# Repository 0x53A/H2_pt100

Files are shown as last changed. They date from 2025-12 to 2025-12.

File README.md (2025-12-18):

This project contains the firmware for the STM32 Nucelo board that's used to measure electrolyte in- and outflow temperatures using PT100 probes at the big ely test station.

The firmware is in ./mcu-stm32g4.

In ./app, there's a small TUI that reads received data from UART.

In ./analysis there's the worksheet that was used for 2-point calibration.

The ROS Node which receives the data ignores the temperatures calculated internally by the firmware (which are inaccurate) and recalculates based on the worksheet:

For board #1:

```
=== Calibration Coefficients ===
PT100 #1: T = 0.008517 * ADC + (-270.186)
PT100 #2: T = 0.008559 * ADC + (-269.970)
```

For board #2:

```
=== Calibration Coefficients ===
PT100 #1: T = 0.008611 * ADC + (-270.310)
PT100 #2: T = 0.008665 * ADC + (-272.644)
```

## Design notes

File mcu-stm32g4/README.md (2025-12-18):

Chip: stm32g431kb

Based on example https://github.com/embassy-rs/embassy/tree/main/examples/stm32g4

## Pin Configuration

### ADC

On the Nucleo Board, CN3:[7,8] (PA5/PA6) are used for I2C, CN3:[5,10] (PA2/PA3) are used for UART. This leaves PA0, PA1, PA4, PA7 as analog-capable pins.

### OpAmp

To use the OpAmp in buffer mode, we need to connect OPAMPx_VINP to the signal we want to measure.

Potential Pins:

| Pin | Func |
| -- | -- |
| PA1 | OPAMP1_VINP, OPAMP3_VINP |
| ~PA3~ | _(PA3 is used for UART)_ |
| PA7 | OPAMP1_VINP, OPAMP2_VINP |
| PB0 | OPAMP2_VINP, OPAMP3_VINP |
| ~PB13~ | OPAMP3_VINP |
| ~PB14~ | OPAMP2_VINP |
| ~PD14~ | OPAMP2_VINP |

### Usage

There is an approximately 3.2 kΩ series resistor between V_3.3 and the PT100. The PT100 are connected via PA7 and PB0 to OpAmp#2, which amplifies the signal by x16 and feeds it into ADC#2.

Data is output through the ST-Link via UART at PA2.

The firmware calculates temperature based on the series resistor values, but that is extremely inaccurate and should be ignored. Instead, the receiver should calculate the temperature based on the raw ADC values and a two-point calculation, which needs to be done for each board seperately.

## Setup

Install Rust using [rustup](https://rustup.rs/).

```sh
# once
cargo install probe-rs-tools

# compile, flash and run, monitor output
cargo run --release

# monitor the output of a running mcu without resetting it
probe-rs attach ./target/thumbv7em-none-eabi/release/pt100_stm32g4 --chip STM32G431KB
```

---

Board:
NUCLEO-G431KB
https://www.st.com/en/evaluation-tools/nucleo-g431kb.html

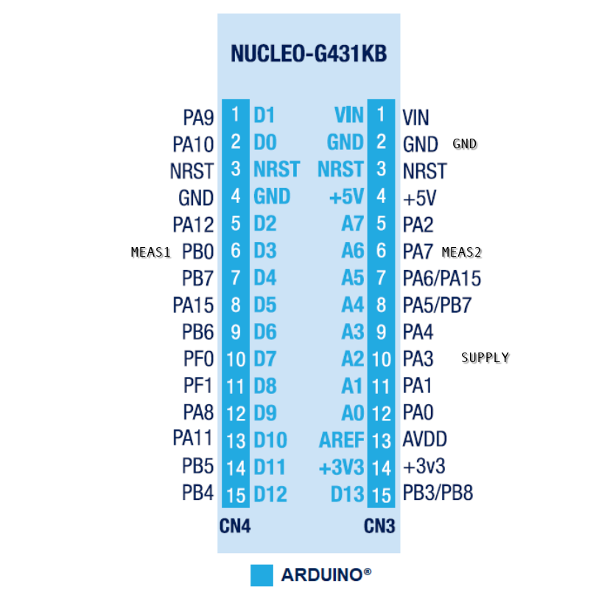
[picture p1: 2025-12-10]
mcu-stm32g4/schematic/Screenshot_20251209_223936.png

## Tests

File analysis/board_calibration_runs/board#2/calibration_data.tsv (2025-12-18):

timestamp | boot_id | sampling_resolution_bits | sampling_sample_time_cycles | sampling_oversampling | sampling_n_measurements | sampling_amplification | pt100_1_series_resistor_ohms | pt100_2_series_resistor_ohms | raw_pt100_1_p20 | raw_pt100_1_median | raw_pt100_1_p80 | raw_pt100_2_p20 | raw_pt100_2_median | raw_pt100_2_p80 | pt100_1_r_pt | pt100_1_temperature | pt100_2_r_pt | pt100_2_temperature
2025-12-17T15:22:55.402Z | 3143733478 | 12 | 640 | 256 | 30 | 16 | 3183.6 | 3203.3 | 31412 | 31418 | 31420 | 31470 | 31475 | 31480 | 98.33666 | -4.320358 | 99.13023 | -2.259133
2025-12-17T15:22:55.677Z | 3143733478 | 12 | 640 | 256 | 30 | 16 | 3183.6 | 3203.3 | 31410 | 31414 | 31416 | 31468 | 31472 | 31475 | 98.32375 | -4.3538876 | 99.12049 | -2.2844388
2025-12-17T15:22:55.952Z | 3143733478 | 12 | 640 | 256 | 30 | 16 | 3183.6 | 3203.3 | 31408 | 31412 | 31418 | 31467 | 31472 | 31477 | 98.3173 | -4.370652 | 99.12049 | -2.2844388
2025-12-17T15:22:56.227Z | 3143733478 | 12 | 640 | 256 | 30 | 16 | 3183.6 | 3203.3 | 31410 | 31414 | 31419 | 31465 | 31471 | 31477 | 98.32375 | -4.3538876 | 99.11724 | -2.2928808
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

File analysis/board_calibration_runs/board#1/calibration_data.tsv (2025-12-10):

timestamp | boot_id | sampling_resolution_bits | sampling_sample_time_cycles | sampling_oversampling | sampling_n_measurements | sampling_amplification | pt100_1_series_resistor_ohms | pt100_2_series_resistor_ohms | raw_pt100_1_p20 | raw_pt100_1_median | raw_pt100_1_p80 | raw_pt100_2_p20 | raw_pt100_2_median | raw_pt100_2_p80 | pt100_1_r_pt | pt100_1_temperature | pt100_2_r_pt | pt100_2_temperature
2025-12-10T13:20:28.790Z | 4221434046 | 12 | 640 | 256 | 10 | 16 | 3183.6 | 3203.3 | 34457 | 34459 | 34463 | 34256 | 34258 | 34263 | 108.17825 | 21.242216 | 108.1913 | 21.276102
2025-12-10T13:20:28.850Z | 4221434046 | 12 | 640 | 256 | 10 | 16 | 3183.6 | 3203.3 | 34453 | 34459 | 34466 | 34256 | 34257 | 34261 | 108.17825 | 21.242216 | 108.188034 | 21.267622
2025-12-10T13:20:28.906Z | 4221434046 | 12 | 640 | 256 | 10 | 16 | 3183.6 | 3203.3 | 34454 | 34459 | 34462 | 34253 | 34255 | 34261 | 108.17825 | 21.242216 | 108.1815 | 21.250658
2025-12-10T13:20:28.962Z | 4221434046 | 12 | 640 | 256 | 10 | 16 | 3183.6 | 3203.3 | 34453 | 34457 | 34463 | 34254 | 34255 | 34259 | 108.17176 | 21.225353 | 108.1815 | 21.250658
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

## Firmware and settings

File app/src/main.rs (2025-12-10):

use anyhow::{Context, Result};
use chrono::Utc;
use clap::Parser;
use common::UartOutput;
use crossterm::{
    event::{self, Event, KeyCode, KeyEventKind},
    terminal::{disable_raw_mode, enable_raw_mode, EnterAlternateScreen, LeaveAlternateScreen},
    ExecutableCommand,
};
use ratatui::{
    backend::CrosstermBackend,
    layout::{Constraint, Direction, Layout, Rect},
    style::{Color, Modifier, Style},
    text::{Line, Span},
    widgets::{Block, Borders, List, ListItem, ListState, Paragraph},
    Frame, Terminal,
};
use std::{
    fs::{File, OpenOptions},
    io::{self, stdout, BufRead, BufReader, Write},
    path::PathBuf,
    time::{Duration, Instant},
};

const COMMON_BAUD_RATES: &[u32] = &[9600, 19200, 38400, 57600, 115200, 230400, 460800, 921600];

#[derive(Parser, Debug)]
#[command(author, version, about, long_about = None)]
struct Args {
    /// Serial port path (e.g., /dev/ttyACM0)
    #[arg(short, long)]
    port: Option<String>,

    /// Baud rate
    #[arg(short, long)]
    baud: Option<u32>,

    /// Log file directory (defaults to current directory)
    #[arg(short, long)]
    log_dir: Option<PathBuf>,
}

#[derive(Clone, Copy, PartialEq)]
enum SelectionMode {
    Port,
    Baud,
}

#[derive(Clone, Copy, PartialEq)]
enum AppState {
    SelectingPort,
    SelectingBaud,
    Connected,
    Disconnected,
}

struct App {
    state: AppState,
    port: Option<String>,
    baud: Option<u32>,
    log_dir: PathBuf,
    log_file: Option<File>,
    last_output: Option<UartOutput>,
    last_received: Option<Instant>,
    available_ports: Vec<String>,
    list_state: ListState,
    error_counter: u32,
    status_message: String,
    last_flush: Instant,
}

impl App {
    fn new(args: Args) -> Self {
        let log_dir = args.log_dir.unwrap_or_else(|| std::env::current_dir().unwrap_or_default());
        
        let initial_state = if args.port.is_none() {
            AppState::SelectingPort
        } else if args.baud.is_none() {
            AppState::SelectingBaud
        } else {
            AppState::Disconnected
        };

        let mut app = App {
            state: initial_state,
            port: args.port,
            baud: args.baud,
            log_dir,
            log_file: None,
            last_output: None,
            last_received: None,
            available_ports: Vec::new(),
            list_state: ListState::default(),
            error_counter: 0,
            status_message: String::new(),
            last_flush: Instant::now(),
        };
        
        if app.state == AppState::SelectingPort {
            app.refresh_ports();
        }
        
        app
    }

    fn refresh_ports(&mut self) {
        self.available_ports = serialport::available_ports()
            .map(|ports| ports.into_iter().map(|p| p.port_name).collect())
            .unwrap_or_default();
        
        if !self.available_ports.is_empty() && self.list_state.selected().is_none() {
            self.list_state.select(Some(0));
        }
    }

    fn select_next(&mut self) {
        let len = match self.state {
            AppState::SelectingPort => self.available_ports.len(),
            AppState::SelectingBaud => COMMON_BAUD_RATES.len(),
            _ => return,
        };
        
        if len == 0 {
            return;
        }
        
        let i = match self.list_state.selected() {
            Some(i) => (i + 1) % len,
            None => 0,
        };
        self.list_state.select(Some(i));
    }

    fn select_previous(&mut self) {
        let len = match self.state {
            AppState::SelectingPort => self.available_ports.len(),
            AppState::SelectingBaud => COMMON_BAUD_RATES.len(),
            _ => return,
        };
        
        if len == 0 {
            return;
        }
        
        let i = match self.list_state.selected() {
            Some(i) => {
                if i == 0 {
                    len - 1
                } else {
                    i - 1
                }
            }
            None => 0,
        };
        self.list_state.select(Some(i));
    }

    fn confirm_selection(&mut self) {
        match self.state {
            AppState::SelectingPort => {
                if let Some(i) = self.list_state.selected() {
                    if let Some(port) = self.available_ports.get(i) {
                        self.port = Some(port.clone());
                        if self.baud.is_none() {
                            self.state = AppState::SelectingBaud;
                            self.list_state.select(Some(4)); // Default to 115200
                        } else {
                            self.state = AppState::Disconnected;
                        }
                    }
                }
            }
            AppState::SelectingBaud => {
                if let Some(i) = self.list_state.selected() {
                    if let Some(&baud) = COMMON_BAUD_RATES.get(i) {
                        self.baud = Some(baud);
                        self.state = AppState::Disconnected;
                    }
                }
            }
            _ => {}
        }
    }

    fn open_log_file(&mut self) -> Result<()> {
        let date = Utc::now().format("%Y-%m-%d_%H-%M-%S");
        let filename = format!("{}-temperatures.tsv", date);
        let path = self.log_dir.join(&filename);
        
        let file_exists = path.exists();
        
        let file = OpenOptions::new()
            .create(true)
            .append(true)
            .open(&path)
            .with_context(|| format!("Failed to open log file: {:?}", path))?;
        
        self.log_file = Some(file);
        
        // Write header if file is new
        if !file_exists {
            self.write_tsv_header()?;
        }
        
        self.status_message = format!("Logging to: {:?}", path);
        Ok(())
    }

    fn write_tsv_header(&mut self) -> Result<()> {
        if let Some(ref mut file) = self.log_file {
            writeln!(
                file,
                "timestamp\tboot_id\t\
                sampling_resolution_bits\tsampling_sample_time_cycles\tsampling_oversampling\tsampling_n_measurements\tsampling_amplification\t\
                pt100_1_series_resistor_ohms\tpt100_2_series_resistor_ohms\t\
                raw_pt100_1_p20\traw_pt100_1_median\traw_pt100_1_p80\t\
                raw_pt100_2_p20\traw_pt100_2_median\traw_pt100_2_p80\t\
                pt100_1_r_pt\tpt100_1_temperature\t\
                pt100_2_r_pt\tpt100_2_temperature"
            )?;
        }
        Ok(())
    }

    fn write_tsv_row(&mut self, output: &UartOutput) -> Result<()> {
        if let Some(ref mut file) = self.log_file {
            let timestamp = Utc::now().format("%Y-%m-%dT%H:%M:%S%.3fZ");
            writeln!(
                file,
                "{}\t{}\t\
                {}\t{}\t{}\t{}\t{}\t\
                {}\t{}\t\
                {}\t{}\t{}\t\
                {}\t{}\t{}\t\
                {}\t{}\t\
                {}\t{}",
                timestamp,
                output.boot_id,
                output.config.sampling.resolution_bits,
                output.config.sampling.sample_time_cycles,
                output.config.sampling.oversampling,
                output.config.sampling.n_measurements,
                output.config.sampling.amplification,
                output.config.pt100_1_series_resistor_ohms,
                output.config.pt100_2_series_resistor_ohms,
                output.raw.pt100_1.p20,
                output.raw.pt100_1.median,
                output.raw.pt100_1.p80,
                output.raw.pt100_2.p20,
                output.raw.pt100_2.median,
                output.raw.pt100_2.p80,
                output.calculated.pt100_1.r_pt,
                output.calculated.pt100_1.temperature,
                output.calculated.pt100_2.r_pt,
                output.calculated.pt100_2.temperature,
            )?;
        }
        Ok(())
    }

    fn flush_if_needed(&mut self) {
        if self.last_flush.elapsed() >= Duration::from_secs(1) {
            self.flush();
        }
    }

    fn flush(&mut self) {
        if let Some(ref mut file) = self.log_file {
            let _ = file.flush();
        }
        self.last_flush = Instant::now();
    }
}

fn main() -> Result<()> {
    let args = Args::parse();
    let mut app = App::new(args);

    // Setup terminal
    enable_raw_mode()?;
    stdout().execute(EnterAlternateScreen)?;
    let backend = CrosstermBackend::new(stdout());
    let mut terminal = Terminal::new(backend)?;

    let result = run_app(&mut terminal, &mut app);

    // Restore terminal
    disable_raw_mode()?;
    stdout().execute(LeaveAlternateScreen)?;

    result
}

fn run_app<B: ratatui::backend::Backend>(terminal: &mut Terminal<B>, app: &mut App) -> Result<()> {
    let mut serial_reader: Option<BufReader<Box<dyn serialport::SerialPort>>> = None;
    let mut line_buffer = String::new();

    loop {
        terminal.draw(|f| ui(f, app))?;

        // Handle connection attempts in Disconnected state
        if app.state == AppState::Disconnected && serial_reader.is_none() {
            if let (Some(port), Some(baud)) = (&app.port, app.baud) {
                match serialport::new(port, baud)
                    .timeout(Duration::from_millis(100))
                    .open()
                {
                    Ok(port) => {
                        serial_reader = Some(BufReader::with_capacity(20_000, port));
                        app.state = AppState::Connected;
                        app.status_message = format!("Connected to {} @ {}", app.port.as_ref().unwrap(), baud);
                        
                        if app.log_file.is_none() {
                            if let Err(e) = app.open_log_file() {
                                app.status_message = format!("Error opening log: {}", e);
                            }
                        }
                    }
                    Err(e) => {
                        app.status_message = format!("Connection failed: {} - retrying...", e);
                        app.refresh_ports();
                    }
                }
            }
        }

        // Read from serial if connected
        if app.state == AppState::Connected {
            if let Some(ref mut reader) = serial_reader {
                line_buffer.clear();
                match reader.read_line(&mut line_buffer) {
                    Ok(0) => {
                        // EOF - disconnected
                        app.state = AppState::Disconnected;
                        app.status_message = "Disconnected (EOF)".to_string();
                        serial_reader = None;
                        app.flush();
                    }
                    Ok(_) => {
                        let line = line_buffer.trim();
                        if !line.is_empty() {
                            match serde_json::from_str::<UartOutput>(line) {
                                Ok(output) => {
                                    if let Err(e) = app.write_tsv_row(&output) {
                                        app.error_counter += 1;
                                        app.status_message = format!("[{}] Write error: {}", app.error_counter, e);
                                    }
                                    app.last_output = Some(output);
                                    app.last_received = Some(Instant::now());
                                }
                                Err(e) => {
                                    app.error_counter += 1;
                                    app.status_message = format!("[{}] Parse error: {} ({})", app.error_counter, e, line[..20].to_string());
                                }
                            }
                        }
                    }
                    Err(ref e) if e.kind() == io::ErrorKind::TimedOut => {
                        // Normal timeout, continue
                    }
                    Err(e) => {
                        app.state = AppState::Disconnected;
                        app.error_counter += 1;
                        app.status_message = format!("[{}] Read error: {}", app.error_counter, e);
                        serial_reader = None;
                        app.flush();
                    }
                }
            }
        }

        app.flush_if_needed();

        // Handle keyboard events (with timeout to not block serial reading)
        if event::poll(Duration::from_millis(50))? {
            if let Event::Key(key) = event::read()? {
                if key.kind == KeyEventKind::Press {
                    match key.code {
                        KeyCode::Char('q') | KeyCode::Esc => {
                            app.flush();
                            return Ok(());
                        }
                        KeyCode::Up | KeyCode::Char('k') => app.select_previous(),
                        KeyCode::Down | KeyCode::Char('j') => app.select_next(),
                        KeyCode::Enter => app.confirm_selection(),
                        KeyCode::Char('r') => {
                            if app.state == AppState::SelectingPort {
                                app.refresh_ports();
                            }
                        }
                        _ => {}
                    }
                }
            }
        }
    }
}

fn ui(f: &mut Frame, app: &App) {
    let chunks = Layout::default()
        .direction(Direction::Vertical)
        .constraints([
            Constraint::Length(3), // Status bar
            Constraint::Min(10),   // Main content
            Constraint::Length(3), // Help bar
        ])
        .split(f.area());

    // Status bar
    let status_text = match app.state {
        AppState::SelectingPort => "Select Serial Port".to_string(),
        AppState::SelectingBaud => "Select Baud Rate".to_string(),
        AppState::Connected => format!(
            "Connected: {} @ {}",
            app.port.as_ref().unwrap_or(&"?".to_string()),
            app.baud.unwrap_or(0)
        ),
        AppState::Disconnected => format!(
            "Disconnected: {} @ {} - Waiting for reconnect...",
            app.port.as_ref().unwrap_or(&"?".to_string()),
            app.baud.unwrap_or(0)
        ),
    };
    
    let status_style = match app.state {
        AppState::Connected => Style::default().fg(Color::Green),
        AppState::Disconnected => Style::default().fg(Color::Yellow),
        _ => Style::default().fg(Color::Cyan),
    };
    
    let status = Paragraph::new(status_text)
        .style(status_style)
        .block(Block::default().borders(Borders::ALL).title("Status"));
    f.render_widget(status, chunks[0]);

    // Main content area
    match app.state {
        AppState::SelectingPort => {
            render_port_selection(f, app, chunks[1]);
        }
        AppState::SelectingBaud => {
            render_baud_selection(f, app, chunks[1]);
        }
        AppState::Connected | AppState::Disconnected => {
            render_temperature_display(f, app, chunks[1]);
        }
    }

    // Help bar
    let help_text = match app.state {
        AppState::SelectingPort => "↑/↓: Navigate | Enter: Select | r: Refresh | q: Quit",
        AppState::SelectingBaud => "↑/↓: Navigate | Enter: Select | q: Quit",
        _ => "q: Quit",
    };
    let help = Paragraph::new(help_text)
        .style(Style::default().fg(Color::DarkGray))
        .block(Block::default().borders(Borders::ALL).title("Help"));
    f.render_widget(help, chunks[2]);
}

fn render_port_selection(f: &mut Frame, app: &App, area: Rect) {
    let items: Vec<ListItem> = app
        .available_ports
        .iter()
        .map(|p| ListItem::new(p.as_str()))
        .collect();

    let list = List::new(items)
        .block(Block::default().borders(Borders::ALL).title("Available Ports"))
        .highlight_style(
            Style::default()
                .bg(Color::Blue)
                .add_modifier(Modifier::BOLD),
        )
        .highlight_symbol(">> ");

    let mut state = app.list_state.clone();
    f.render_stateful_widget(list, area, &mut state);
}

fn render_baud_selection(f: &mut Frame, app: &App, area: Rect) {
    let items: Vec<ListItem> = COMMON_BAUD_RATES
        .iter()
        .map(|&b| ListItem::new(format!("{} baud", b)))
        .collect();

    let list = List::new(items)
        .block(Block::default().borders(Borders::ALL).title("Select Baud Rate"))
        .highlight_style(
            Style::default()
                .bg(Color::Blue)
                .add_modifier(Modifier::BOLD),
        )
        .highlight_symbol(">> ");

    let mut state = app.list_state.clone();
    f.render_stateful_widget(list, area, &mut state);
}

fn render_temperature_display(f: &mut Frame, app: &App, area: Rect) {
    let chunks = Layout::default()
        .direction(Direction::Vertical)
        .constraints([
            Constraint::Length(5),  // Temperatures
            Constraint::Length(3),  // Time since last
            Constraint::Length(6),  // Raw data
            Constraint::Min(3),     // Status message
        ])
        .split(area);

    // Temperature display
    let temp_text = if let Some(ref output) = app.last_output {
        vec![
            Line::from(vec![
                Span::styled("PT100 #1: ", Style::default().fg(Color::Cyan)),
                Span::styled(
                    format!("{:.2}°C", output.calculated.pt100_1.temperature),
                    Style::default().fg(Color::White).add_modifier(Modifier::BOLD),
                ),
                Span::raw(format!("  (R = {:.2}Ω)", output.calculated.pt100_1.r_pt)),
            ]),
            Line::from(vec![
                Span::styled("PT100 #2: ", Style::default().fg(Color::Cyan)),
                Span::styled(
                    format!("{:.2}°C", output.calculated.pt100_2.temperature),
                    Style::default().fg(Color::White).add_modifier(Modifier::BOLD),
                ),
                Span::raw(format!("  (R = {:.2}Ω)", output.calculated.pt100_2.r_pt)),
            ]),
            Line::from(vec![
                Span::styled("Boot ID: ", Style::default().fg(Color::DarkGray)),
                Span::raw(format!("{}", output.boot_id)),
            ]),
        ]
    } else {
        vec![Line::from("Waiting for data...")]
    };

    let temps = Paragraph::new(temp_text)
        .block(Block::default().borders(Borders::ALL).title("Temperatures"));
    f.render_widget(temps, chunks[0]);

    // Time since last received
    let time_text = if let Some(last) = app.last_received {
        let elapsed = last.elapsed();
        let secs = elapsed.as_secs();
        if secs < 60 {
            format!("{} seconds ago", secs)
        } else {
            format!("{}:{:02} ago", secs / 60, secs % 60)
        }
    } else {
        "Never".to_string()
    };
    
    let time_style = if let Some(last) = app.last_received {
        if last.elapsed() > Duration::from_secs(5) {
            Style::default().fg(Color::Yellow)
        } else {
            Style::default().fg(Color::Green)
        }
    } else {
        Style::default().fg(Color::DarkGray)
    };

    let time_widget = Paragraph::new(time_text)
        .style(time_style)
        .block(Block::default().borders(Borders::ALL).title("Last Received"));
    f.render_widget(time_widget, chunks[1]);

    // Raw data display
    let raw_text = if let Some(ref output) = app.last_output {
        vec![
            Line::from(vec![
                Span::styled("Raw PT100 #1: ", Style::default().fg(Color::Cyan)),
                Span::raw(format!(
                    "p20={}, median={}, p80={}",
                    output.raw.pt100_1.p20, output.raw.pt100_1.median, output.raw.pt100_1.p80
                )),
            ]),
            Line::from(vec![
                Span::styled("Raw PT100 #2: ", Style::default().fg(Color::Cyan)),
                Span::raw(format!(
                    "p20={}, median={}, p80={}",
                    output.raw.pt100_2.p20, output.raw.pt100_2.median, output.raw.pt100_2.p80
                )),
            ]),
            Line::from(vec![
                Span::styled("Sampling: ", Style::default().fg(Color::DarkGray)),
                Span::raw(format!(
                    "{}bit, {}cyc, {}x oversample, {}meas, {}x amp",
                    output.config.sampling.resolution_bits,
                    output.config.sampling.sample_time_cycles,
                    output.config.sampling.oversampling,
                    output.config.sampling.n_measurements,
                    output.config.sampling.amplification
                )),
            ]),
            Line::from(vec![
                Span::styled("Series R: ", Style::default().fg(Color::DarkGray)),
                Span::raw(format!(
                    "PT100#1={}Ω, PT100#2={}Ω",
                    output.config.pt100_1_series_resistor_ohms,
                    output.config.pt100_2_series_resistor_ohms
                )),
            ]),
        ]
    } else {
        vec![Line::from("No data yet")]
    };

    let raw_widget = Paragraph::new(raw_text)
        .style(Style::default().fg(Color::White))
        .block(Block::default().borders(Borders::ALL).title("Raw Data"));
    f.render_widget(raw_widget, chunks[2]);

    // Status message
    let status = Paragraph::new(app.status_message.as_str())
        .style(Style::default().fg(Color::DarkGray))
        .block(Block::default().borders(Borders::ALL).title("Log"));
    f.render_widget(status, chunks[3]);
}

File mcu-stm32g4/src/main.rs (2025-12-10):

#![no_std]
#![no_main]

use defmt::*;
use embassy_executor::Spawner;
use embassy_stm32::adc::vals::{Rovsm, Trovs};
use embassy_stm32::adc::{Adc, AdcConfig, Dual, Resolution, SampleTime};
use embassy_stm32::gpio::{Level, Output, Speed};
use embassy_stm32::opamp::{OpAmp, OpAmpGain, OpAmpSpeed};
use embassy_stm32::rng::Rng;
use embassy_stm32::usart::UartTx;
use embassy_stm32::{bind_interrupts, opamp};
use embassy_time::{Delay, Duration, Ticker};
use embedded_hal::delay::DelayNs as _;
use heapless::String;
use heapless::Vec;
use serde::Serialize;
use {defmt_rtt as _, panic_probe as _};

use common::*;

bind_interrupts!(struct Irqs {
    RNG => embassy_stm32::rng::InterruptHandler<embassy_stm32::peripherals::RNG>;
});

const R_SERIES_1: f32 = 3183.6;
const R_SERIES_2: f32 = 3203.3;

#[embassy_executor::main]
async fn main(_spawner: Spawner) -> ! {
    info!("Boot");

    let mut config = embassy_stm32::Config::default();
    {
        use embassy_stm32::rcc::mux::*;
        use embassy_stm32::rcc::*;
        config.rcc.pll = Some(Pll {
            source: PllSource::HSI,
            prediv: PllPreDiv::DIV4,
            mul: PllMul::MUL85,
            divp: None,
            divq: Some(PllQDiv::DIV4),
            divr: Some(PllRDiv::DIV2),
        });
        config.rcc.mux.adc12sel = Adcsel::SYS;
        config.rcc.sys = Sysclk::PLL1_R;
        config.rcc.ahb_pre = AHBPrescaler::DIV1;
    }

    let mut p = embassy_stm32::init(config);

    info!("Clocks initialized");

    // --------------------------------------------------
    // Init peripherals
    // --------------------------------------------------

    let mut rng = Rng::new(p.RNG, Irqs);
    let id = rng.next_u32();

    // UART
    let mut usart = UartTx::new(
        p.USART2,
        p.PA2,
        p.DMA2_CH6,
        embassy_stm32::usart::Config::default(),
    )
    .unwrap();

    // status LED
    let mut led_status = Output::new(p.PB8, Level::High, Speed::Low);

    // GPIO out
    // Note: currently the GPIO is always on,
    //   but if measurement frequency is reduced,
    //   it could be switched off between measurements to reduce pt100 self-heating

    // let mut gpio_out_1 = Output::new(p.PA4, Level::High, Speed::Low);
    // gpio_out_1.set_high();

    // let mut gpio_out_2 = Output::new(p.PA15, Level::High, Speed::Low);
    // gpio_out_2.set_high();

    // loop {

    // }

    // --------------------------------------------------
    // ADC Pin Configuration for PT100 sensors
    // --------------------------------------------------

    // PT100 sensor ADC pins
    let mut pt100_pin_1 = p.PA7;
    let mut pt100_pin_2 = p.PB0;

    // let mut opamp1 = OpAmp::new(p.OPAMP1, OpAmpSpeed::Normal);
    // opamp1.calibrate();

    let mut opamp2 = OpAmp::new(p.OPAMP2, OpAmpSpeed::Normal);
    opamp2.calibrate();

    // // Initialize ADC
    // let mut adc1 = Adc::new(
    //     p.ADC1,
    //     AdcConfig {
    //         dual_mode: None,
    //         oversampling_mode: Some((Rovsm::CONTINUED, Trovs::AUTOMATIC, true)),
    //         oversampling_ratio: Some(0b111), // 256x
    //         oversampling_shift: Some(4),
    //         resolution: Some(Resolution::BITS12),
    //     },
    // );

    // Initialize ADC2
    let mut adc2 = Adc::new(
        p.ADC2,
        AdcConfig {
            dual_mode: None,
            oversampling_mode: Some((Rovsm::CONTINUED, Trovs::AUTOMATIC, true)),
            oversampling_ratio: Some(0b111), // 256x
            oversampling_shift: Some(4),     //Some(4),
            resolution: Some(Resolution::BITS12),
        },
    );

    // ------------------------

    info!("Peripherals initialized!");

    let mut delay: Delay = Delay;
    delay.delay_ms(100);

    info!("Starting measurement loop");

    // let mut ticker = Ticker::every(Duration::from_millis(100));

    loop {
        const N_MEASUREMENTS: usize = 30;

        led_status.toggle();

        let mut values_pt100_1: Vec<u16, N_MEASUREMENTS> = Vec::new();
        let mut values_pt100_2: Vec<u16, N_MEASUREMENTS> = Vec::new();

        for _ in 0..N_MEASUREMENTS {
            // --------------------------------------------------
            // Read PT100 sensor values
            // --------------------------------------------------

            {
                let mut pt100_1 = opamp2.pga_int(pt100_pin_1.reborrow(), OpAmpGain::Mul16);
                let value = adc2.blocking_read(&mut pt100_1, SampleTime::CYCLES640_5);
                let _ = values_pt100_1.push(value);
            }

            {
                let mut pt100_2 = opamp2.pga_int(pt100_pin_2.reborrow(), OpAmpGain::Mul16);
                let value = adc2.blocking_read(&mut pt100_2, SampleTime::CYCLES640_5);
                let _ = values_pt100_2.push(value);
            }
        }

        // --------------------------------------------------
        // Calculate median values
        // --------------------------------------------------

        let stats_pt100_1 = calculate_median(&mut values_pt100_1);
        let stats_pt100_2 = calculate_median(&mut values_pt100_2);

        // --------------------------------------------------
        // Convert ADC values to temperature
        // --------------------------------------------------

        let temp_pt100_1 = adc_to_temp(stats_pt100_1.median, R_SERIES_1, 16);
        let temp_pt100_2 = adc_to_temp(stats_pt100_2.median, R_SERIES_2, 16);

        // --------------------------------------------------
        // Output values
        // --------------------------------------------------

        info!(
            "1: {} (+{} -{}) | 2: {} (+{} -{})",
            stats_pt100_1.median,
            stats_pt100_1.p80 - stats_pt100_1.median,
            stats_pt100_1.median - stats_pt100_1.p20,
            stats_pt100_2.median,
            stats_pt100_2.p80 - stats_pt100_2.median,
            stats_pt100_2.median - stats_pt100_2.p20,
        );

        // Output via UART as JSON
        let output = UartOutput {
            boot_id: id,
            config: Config {
                sampling: SamplingConfig {
                    resolution_bits: 12,
                    sample_time_cycles: 640,
                    oversampling: 256,
                    n_measurements: N_MEASUREMENTS as u16,
                    amplification: 16,
                },
                pt100_1_series_resistor_ohms: R_SERIES_1,
                pt100_2_series_resistor_ohms: R_SERIES_2,
            },
            raw: RawMeasurements {
                pt100_1: stats_pt100_1,
                pt100_2: stats_pt100_2,
            },
            calculated: Temperatures {
                pt100_1: temp_pt100_1,
                pt100_2: temp_pt100_2,
            },
        };
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

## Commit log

2025-07-14 latest changes
    [pinout.kicad_pcb, pinout.kicad_sch]
2025-12-06 add STM32G4 version
2025-12-10 pt100 mcu reading firmware and calibration notebook - this version is actually used
    [calibration_data.tsv]
2025-12-18 add calibration data for second board
    [calibration_data.tsv]
